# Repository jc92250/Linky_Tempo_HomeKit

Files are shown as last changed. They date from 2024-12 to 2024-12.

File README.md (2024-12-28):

# Linky_Tempo_HomeKit

** work in progress **  
Status actuel: démontrateur technique de la partie HomeKit sur platine d'essai

## Présentation

Ceci est la "V2" du projet Linky_Tempo.  
L'objectif est de pouvoir accéder au status du délestage ainsi qu'à la possibilité d'annuler ce délestage depuis Internet.

L'approche suivie sera de:
- remplacer l'Arduino par un ESP32
- installer HomeSpan sur l'ESP32 pour qu'il soit vu comme un device HomeKit
- le configurer comme un "Thermostat"

Pourquoi "Thermostat" ?  
Car cela semble être le device dont les fonctionnalités sont les plus proches de celles qu'on veut obtenir.  
Voici ses différents modes de fonctionnement (CurrentHeatingCoolingState) et leur usage prévu:
- IDLE: utilisé, délestage possible en fonction des infos du Linky
- HEATING: délestage annulé, chauffage actif
- COOLING: pas utilisé

Concernant la commande (TargetHeatingCoolingState) on a:
- OFF: pas utilisé
- HEAT: annulation du délestage, activer le chauffage (sauf si surconsommation)
- COOL: pas utilisé
- AUTO: mode automatique (délestage HPJR, HPJW et surconsommation)

Le circuit a également un bouton poussoir permettant de basculer entre le mode automatique et le mode annulation du délestage

Note: "Heater-Cooler" aurait peut-être pu être utilisé à la place de "Thermostat". Mais cette possibilité n'a pas été étudiée.

## Configuration

Factory reset:  
Faire un appui long (> 10 secondes) sur le bouton reset. Au bout de 3 secondes, la led interne va clignoter rapidement, continuer l'appui sur le bouton jusqu'à l'extinction de la led.

A ce moment, le device est configuré comme un point d'accès wifi sur lequel on peut
se connecter avec un ordinateur ou un smartphone. Voici les paramètres du point d'accès:
- nom du wifi: JCDELESTAGE
- mot de passe: 123456789

Via ce point d'accès, il est possible de:
- définit le réseau wifi sur lequel le device doit se connecter
- définir le setup-code homeKit du device

Une fois ces informations saisies, le device va redémarrer et ce connecteur à ce
réseau wifi. Une fois ceci effectué, la led bleue va flasher 2 fois toutes les 3 secondes
pour indiquer qu'il n'est pas pairé dans Maison.

## Les LEDs

LED rouge: toujours allumée, indique que l'ESP32 est alimenté  
LED bleue:  
- allumée fixe: le device est en fonctionnement et pairé dans Maison  
- allumée et clignotante (2 flashs brefs toutes les 3 secondes): le device n'est pas pairé dans Maison

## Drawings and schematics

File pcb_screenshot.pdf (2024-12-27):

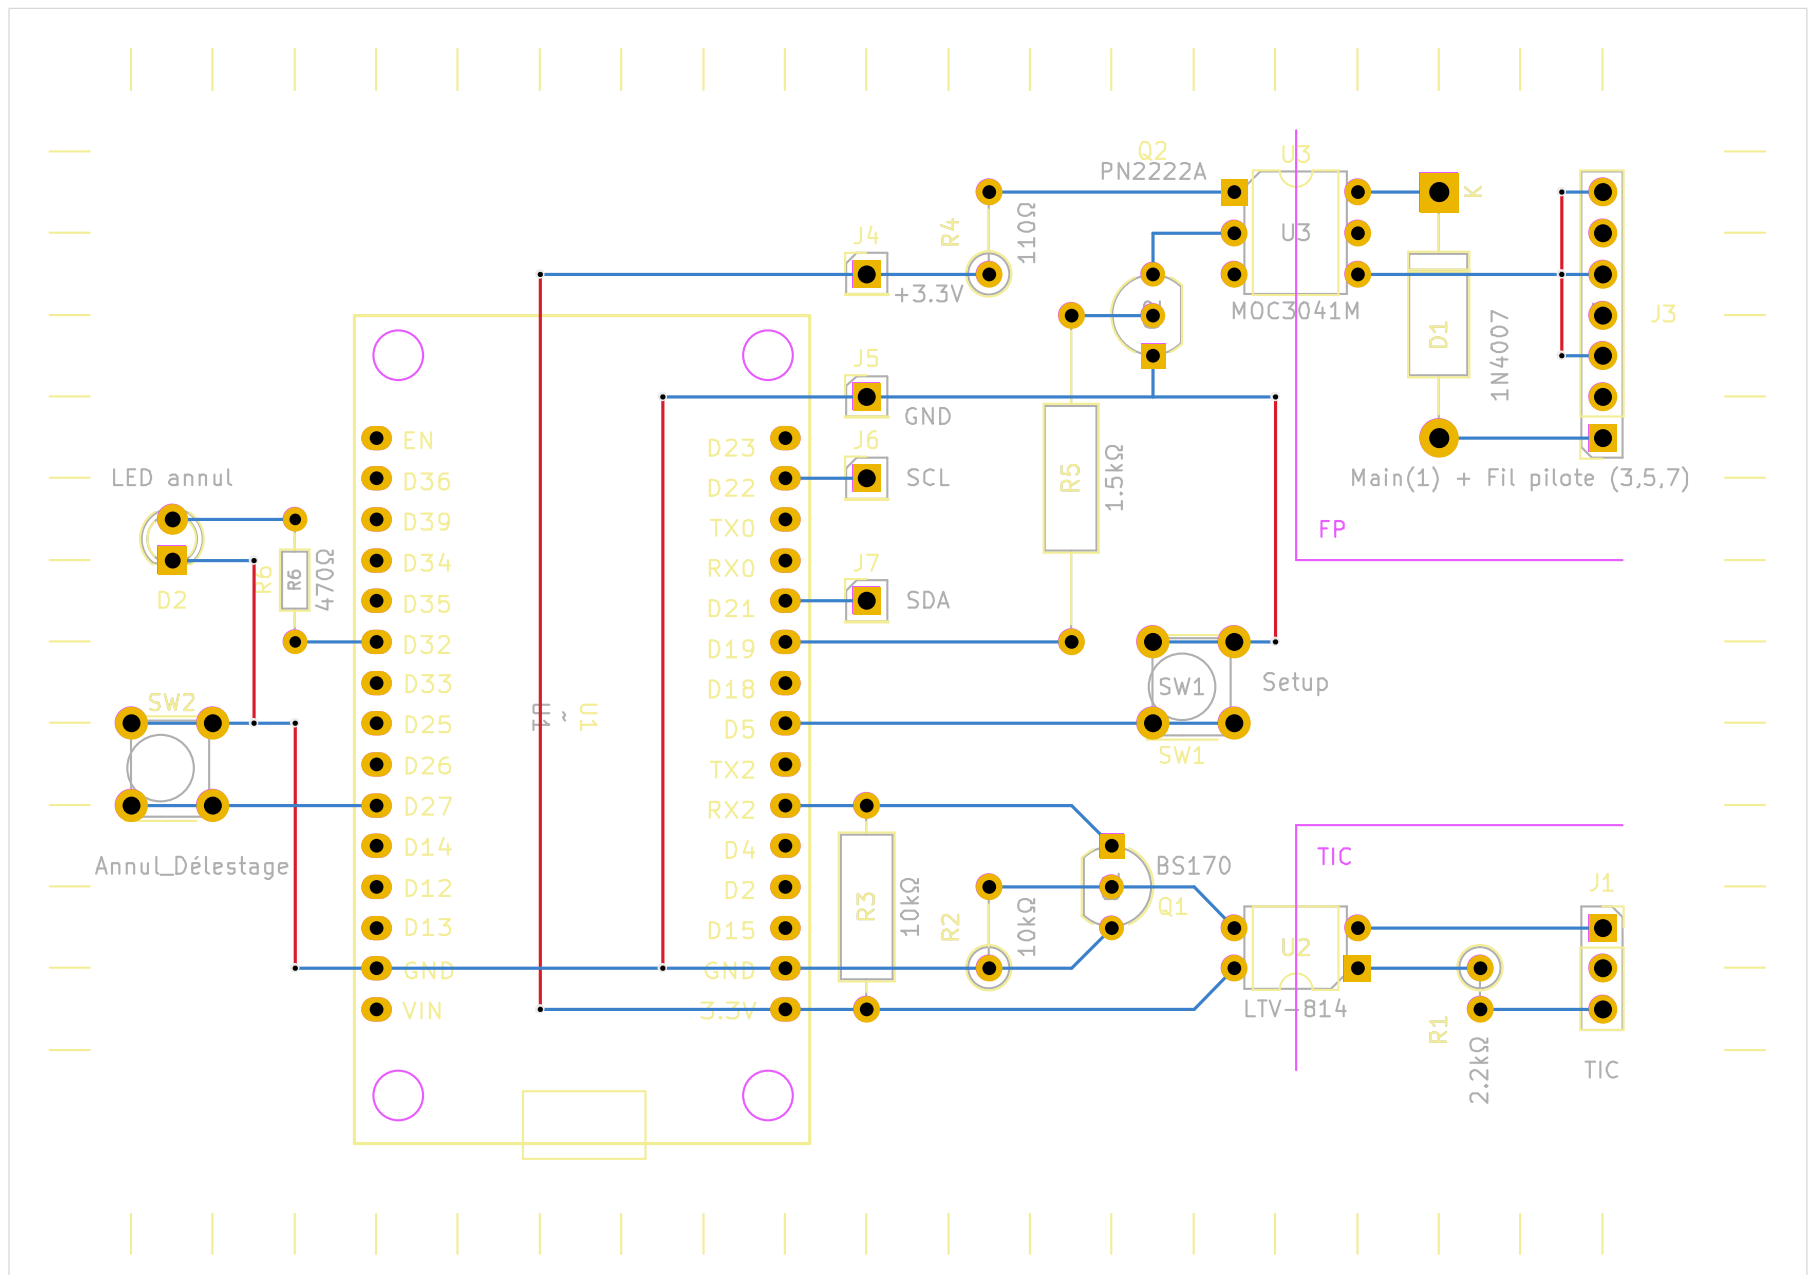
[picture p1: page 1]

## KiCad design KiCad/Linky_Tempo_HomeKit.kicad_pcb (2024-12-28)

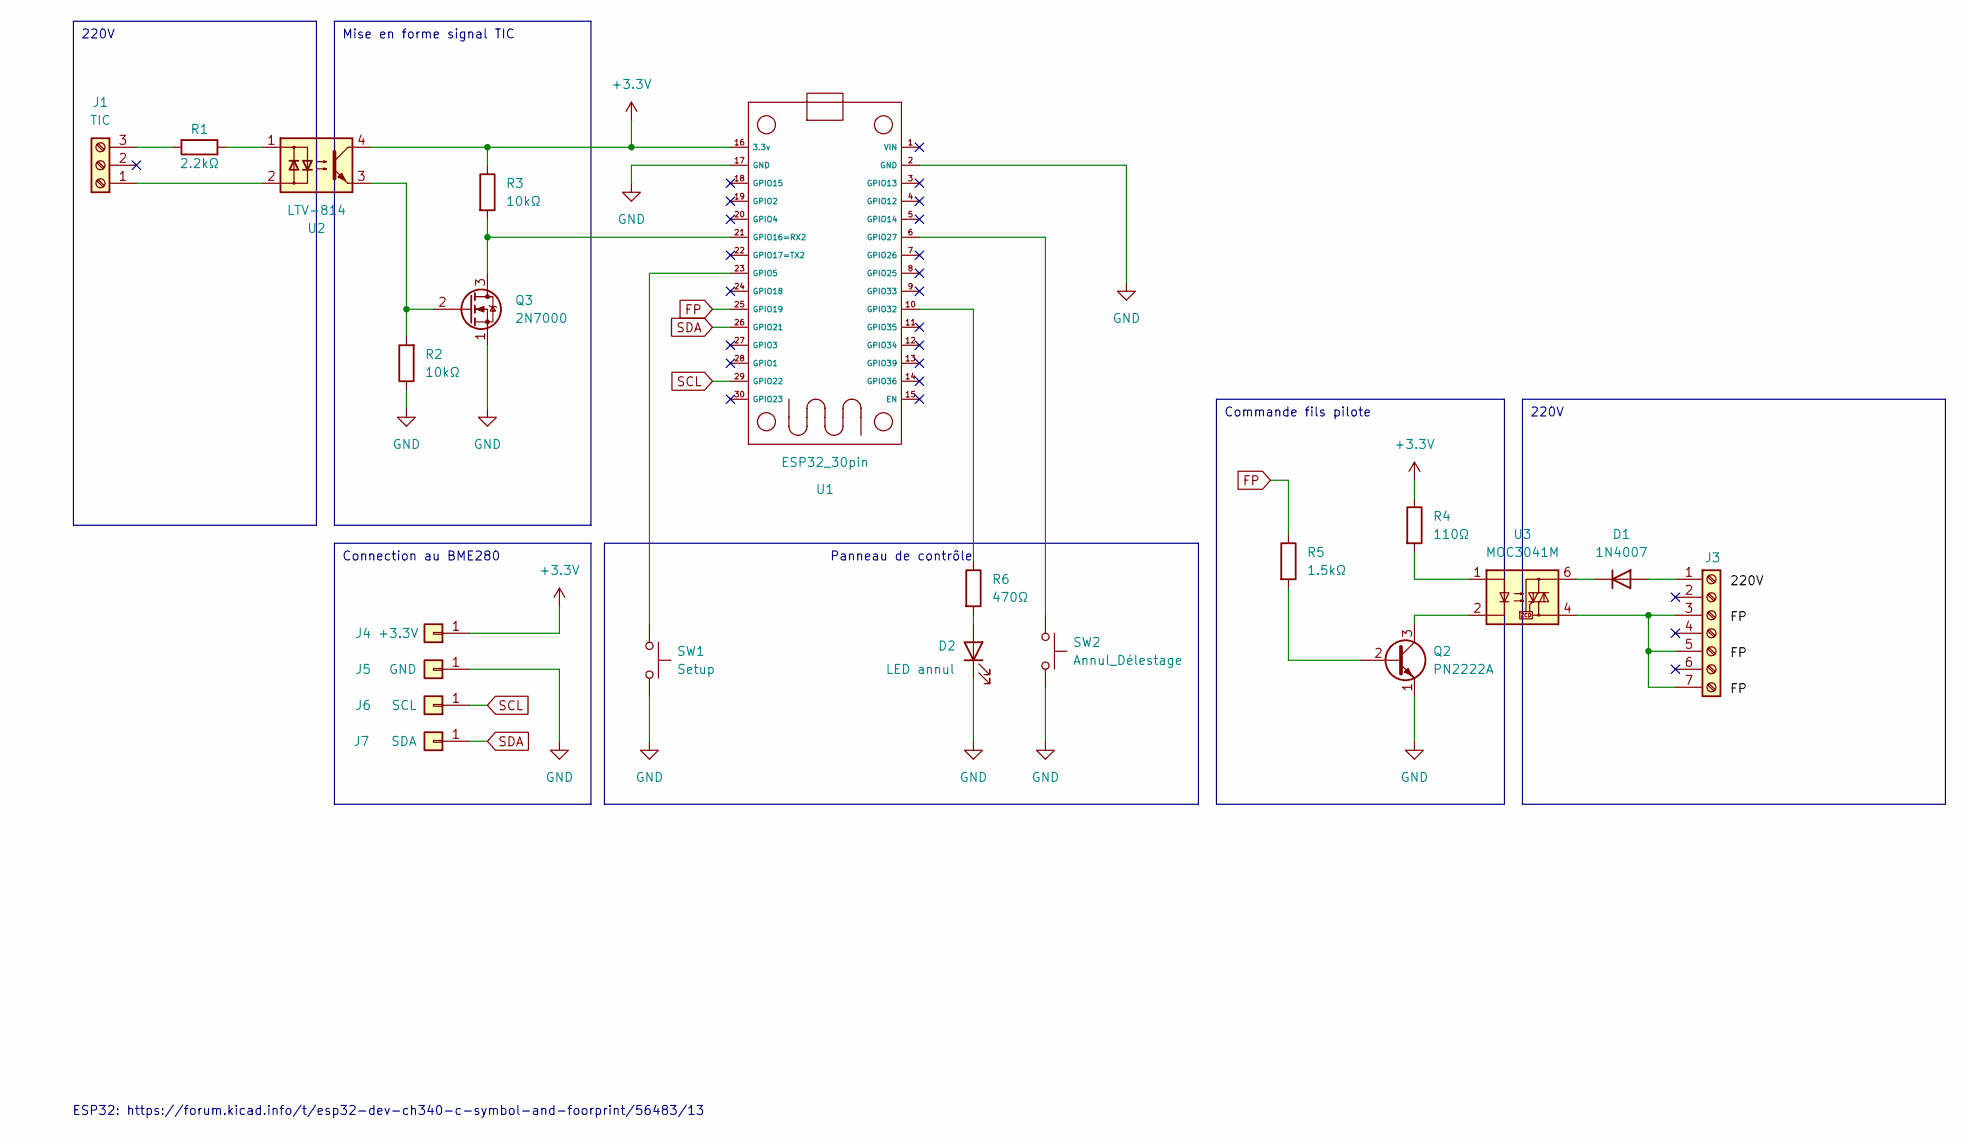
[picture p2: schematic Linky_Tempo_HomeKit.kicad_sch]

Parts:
D1: 1N4007; D_DO-15_P15.24mm_Horizontal
D2: LED annul; LED_D3.0mm
J1: TIC; PinSocket_1x03_P2.54mm_Vertical
J3: Main(1) + Fil pilote (3,5,7); PinSocket_1x07_P2.54mm_Vertical
J4: +3.3V; PinHeader_1x01_P2.54mm_Vertical
J5: GND; PinHeader_1x01_P2.54mm_Vertical
J6: SCL; PinHeader_1x01_P2.54mm_Vertical
J7: SDA; PinHeader_1x01_P2.54mm_Vertical
Q2: PN2222A; TO-92_Inline_Wide
Q3: 2N7000; TO-92_Inline
R1: 2.2kΩ; R_Axial_DIN0207_L6.3mm_D2.5mm_P2.54mm_Vertical
R2: 10kΩ; R_Axial_DIN0207_L6.3mm_D2.5mm_P2.54mm_Vertical
R3: 10kΩ; R_Axial_DIN0309_L9.0mm_D3.2mm_P12.70mm_Horizontal
R4: 110Ω; R_Axial_DIN0207_L6.3mm_D2.5mm_P5.08mm_Vertical
R5: 1.5kΩ; R_Axial_DIN0309_L9.0mm_D3.2mm_P20.32mm_Horizontal
R6: 470Ω; R_Axial_DIN0204_L3.6mm_D1.6mm_P7.62mm_Horizontal
SW1: Setup; SW_PUSH_5.08mm_H5mm
SW2: Annul_Délestage; SW_PUSH_5.08mm_H5mm
U1: ESP32_30pin
U2: LTV-814; DIP-4_W7.62mm
U3: MOC3041M; DIP-6_W7.62mm

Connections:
+3.3V: J4.1, R3.1, R4.1, U1.16 (3.3v), U2.4
FP: R5.1, U1.25 (GPIO19)
GND: D2.1 (K), J5.1, Q2.1 (E), Q3.1 (S), R2.1, SW1.2, SW2.2, U1.2 (GND), U1.17 (GND)
unnamed: D1.2 (A), J3.1
unnamed: D1.1 (K), U3.6
unnamed: D2.2 (A), R6.2
unnamed: J1.1, U2.2
unnamed: J1.3, R1.2
unnamed: J3.3, J3.5, J3.7, U3.4
unnamed: Q2.2 (B), R5.2
unnamed: Q2.3 (C), U3.2
unnamed: Q3.3 (D), R3.2, U1.21 (GPIO16=RX2)
unnamed: Q3.2 (G), R2.2, U2.3
unnamed: R1.1, U2.1
unnamed: R4.2, U3.1
unnamed: SW1.1, U1.23 (GPIO5)
unnamed: SW2.1, U1.6 (GPIO27)
unnamed: R6.1, U1.10 (GPIO32)
SCL: J6.1, U1.29 (GPIO22)
SDA: J7.1, U1.26 (GPIO21)

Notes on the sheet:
Connection au BME280
Commande fils pilote
220V
Panneau de contrôle
Mise en forme signal TIC
ESP32: https://forum.kicad.info/t/esp32-dev-ch340-c-symbol-and-foorprint/56483/13

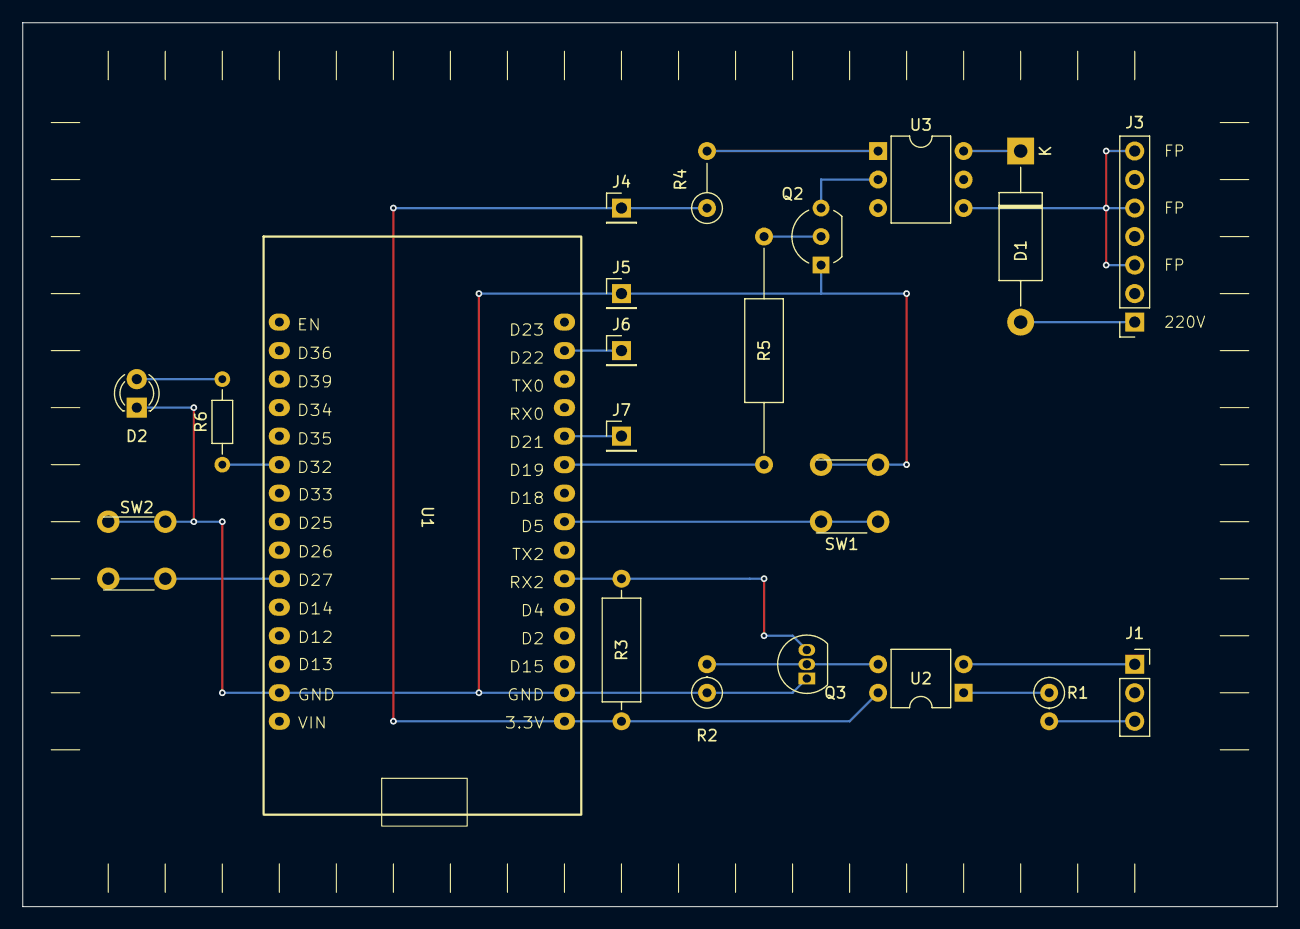
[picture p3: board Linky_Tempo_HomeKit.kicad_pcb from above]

Board: 2 copper layers, 111.8 x 78.7 mm, 21 parts (0 on the bottom side), 20 nets.

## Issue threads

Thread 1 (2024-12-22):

changement de la target température

jc92250, 2024-12-22:
L'utilisateur peut déjà changer le mode (entre auto et chauffage) de plusieurs façons:
- clicker sur le bouton physique
- sélectionner auto ou chauffage dans l'appli Maison
L'idée serait de permettre de changer (entre auto et chauffage) en changeant la température Target. Par exemple:
- en la définissant à 21°C ou plus, le système bascule en mode chauffage
- en la définissant à 16°C ou moins, le système bascule en mode auto

jc92250, 2024-12-24:
implémenté

Closed 2024-12-24.

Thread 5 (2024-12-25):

la tempo de délestage ne devrait être active que lors d'une surconsommation

jc92250, 2024-12-25:
Le comportement devrait être le suivant:
surconsommation ==> le délestage doit durer un certain temps
annulation du délectage ==> immédiat
délestage HPJR et HPJW ==> immédiat

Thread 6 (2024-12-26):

en mode délestage interdit, parfois la température ne redescend pas à 10°C

jc92250, 2024-12-26:
Etat initial: délestage. Maison affiche 10,0 et Autom.
Passer en mode Chauffer. Maison affiche 21,0 puis repasse en Autom.
Mais la température reste à 21,0

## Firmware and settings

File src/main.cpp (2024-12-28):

//
// ----------------------------------------------------------------
// Issues:
//
// TODO: passer sur la v2 de homeSpan
// TODO: vérifier qu'on peut uploader un nouveau sketch en étant connecté à la TIC
// TODO: led qui confirme le fonctionnement normal (homespan + bme280) ?
// TODO: fonctionnement en cas de 'plantage' de la partie HomeKit ?
// TODO: juste après l'upload du sketch, passer en chauffage ne se reset pas bien
// TODO: passer en 'Chauffer': affiche chauffage mais la température reste à 10°C
//
// DONE: activer le hotspot wifi immédiatement après un reset
// DONE: la tempo de délestage ne doit s'appliquer qu'à la surconsommation
// DONE: en délestage interdit, la température reste parfois à 21°C
// DONE: en délestage interdit, on reste parfois en mode chauffage
// ----------------------------------------------------------------
//
#include "constants.h"
//#include "wifi_JC.h"

// ----------------------------------------------------------------
// Téléinformation Linky
// Important: la téléinformation est reçue sur Serial2 = UART2
// (on réserve Serial = UART0 pour la programmation de l'ESP et
// les logs)
// ----------------------------------------------------------------
#include "LibTeleinfo.h"
#include "setup_detect_TIC_mode.h"
#include "callbacks.h"

// Dans quel mode est la TIC (standard ou historique ?) 
_Mode_e mode_tic;

// L'objet qui permet de récupérer le détail de la TIC
// Plus d'info ici: https://hallard.me/libteleinfo/
TInfo tinfo;

// L'utilisateur a-t-il demandé une annulation du délestage ?
// Si oui, depuis quand
bool annulDelestageHPJW;
uint32_t startDelestage;


// ----------------------------------------------------------------
// Capteur de température et humidité BME280
// ----------------------------------------------------------------
#include <Wire.h>
#include <Adafruit_Sensor.h>
#include <Adafruit_BME280.h>

Adafruit_BME280 bme280; // I2C
boolean bHasBME280 = true;


// ----------------------------------------------------------------
// HomeSpan (intégration HomeKit)
// ----------------------------------------------------------------
#include "HomeSpan.h"
#include "DEV_Thermostat.h"

DEV_Thermostat *thermostat;


// ----------------------------------------------------------------
// setup
// ----------------------------------------------------------------
void setup() {
  Serial.begin(9600);

  // Linky --------------------------------------------------------
  annulDelestageHPJW  = false;

  // BME280, with default settings --------------------------------
  unsigned status = bme280.begin(0x76);
  if (!status) {
    Serial.println("Could not find a valid BME280 sensor, check wiring, address, sensor ID!");
    Serial.print("SensorID was: 0x"); Serial.println(bme280.sensorID(),16);
    Serial.print("        ID of 0xFF probably means a bad address, a BMP 180 or BMP 085\n");
    Serial.print("   ID of 0x56-0x58 represents a BMP 280,\n");
    Serial.print("        ID of 0x60 represents a BME 280.\n");
    Serial.print("        ID of 0x61 represents a BME 680.\n");
    bHasBME280 = false;
  }

  // Commandes ----------------------------------------------------
  pinMode(PIN_SETUP, INPUT_PULLUP);  // bouton poussoir pour entrer en mode setup
  pinMode(LED_ANNUL, OUTPUT);        // la LED jaune qui indique qu'on a annulé le délestage

  // HomeSpan -----------------------------------------------------

  // Controle du device: un bouton et une LED
  pinMode(PIN_LED, OUTPUT);         // builtin led

  // Bouton poussoir pour annuler le délestage automatique
  // Premier appui: on annule le délestage (chauffage selon la programmation des radiateurs)
  // Second appui: on reviens en mode automatique (délestage)
  pinMode(PIN_ANNUL_DELEST, INPUT_PULLUP);

  homeSpan.setStatusPin(PIN_LED);   // led
  homeSpan.setControlPin(PIN_SETUP); // bouton
  //homeSpan.setLogLevel(2);
  // Le WiFi interne utilisé lors de la configuration du device
  homeSpan.enableAutoStartAP(); // le mode point d'accès wifi sera actif automatiquement après un reset
  homeSpan.setApSSID(APSSID);
  homeSpan.setApPassword(APPASSWORD);
  // TEMPORAIRE:
  //homeSpan.setWifiCredentials(WIFI_SSID, WIFI_PASSWORD);
  //homeSpan.setPairingCode(PAIRING_CODE);
  //homeSpan.setLogLevel(1);
  // Définition de l'accessoire
  homeSpan.begin(Category::Thermostats, DISPLAY_NAME, HOST_NAME_BASE, MODEL_NAME);

  new SpanAccessory();
  new Service::AccessoryInformation();
  new Characteristic::Identify();
  thermostat = new DEV_Thermostat(bHasBME280 ? &bme280 : nullptr);

  homeSpan.autoPoll();
}


// ----------------------------------------------------------------
// loop
// ----------------------------------------------------------------
void loop() {
  // réception d'un caractère de la TIC
  // on laisse tinfo essayer de décoder l'ensemble
  if (Serial2.available()) tinfo.process(Serial2.read());

  // Délestage
  uint32_t currentTime = millis();

  // l'utilisateur a demandé d'annuler le délestage ?
  annulDelestageHPJW = thermostat->heatEnforced();
  digitalWrite(LED_ANNUL, annulDelestageHPJW ? HIGH : LOW);

  // On ne peut annuler le délestage qu'en HPJW
  // On s'assure donc que ette annulation ne reste pas active trop longtemps
  if (annulDelestageHPJW && !delestage_HPJW) {
    thermostat->enforceAuto();
    annulDelestageHPJW = false;
    //digitalWrite(LED_ANNUL, LOW);
  }

  // on indique au fil pilote si on déleste ou pas
  if (delestage_CONSO) {
    // On doit délester pour cause de surconsommation
    // Comme on ne sait pas si on était déjà en mode délestage, on définit les pins de sortie en conséquence
    digitalWrite(PIN_PILOTE, HIGH);
    // En on repousse la fin du délestage
    startDelestage = currentTime;

  } else if (delestage_HPJR) {
    // On doit délester pour cause de jour rouge
    // Comme on ne sait pas si on était déjà en mode délestage, on définit les pins de sortie en conséquence
    digitalWrite(PIN_PILOTE, HIGH);

  } else if (delestage_HPJW && !annulDelestageHPJW) {
    // On doit délester pour cause de jour blanc
    // Comme on ne sait pas si on était déjà en mode délestage, on définit les pins de sortie en conséquence
    digitalWrite(PIN_PILOTE, HIGH);

  } else if (currentTime - startDelestage > TEMPS_DELESTAGE) {
    // On n'a plus besoin de délester
    // et ceci, depuis assez longtemps (TEMPS_DELESTAGE)
    // Ce temps d'attente est pour éviter de basculer trop souvent
    // Par exemple, lorsque le four ou une plaque de cuisson est en maintient de température
    // On peut enfin annuler le délestage
    // TODO: LED_Eteinte();
    digitalWrite(PIN_PILOTE, LOW);
  }
}

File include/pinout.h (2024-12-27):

//
// ----------------------------------------------------------------
// Les différents Pins de l'ESP
// ----------------------------------------------------------------

// builtin led pour homeSpan
#define PIN_LED           2

// bouton poussoir pour homeSpan (pour faire le setup du device)
#define PIN_SETUP         5

// Sortie qui commande le fil pilote
#define PIN_PILOTE       19

// bouton poussoir pour annuler le délestage
// note: on ne peut annuler le délestage qu'en HPJW (heure pleine jour blanc)
#define PIN_ANNUL_DELEST 27

// LED jaune allumée si le delestage a été annulé
#define LED_ANNUL        32

// La TIC du linky est reçue sur Serial2()

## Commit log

2024-12-28 corrections diverses
    [Linky_Tempo_HomeKit.kicad_pcb, Linky_Tempo_HomeKit.kicad_sch]
2024-12-28 hotspot activé automatiquement après reset
    [main.cpp]
